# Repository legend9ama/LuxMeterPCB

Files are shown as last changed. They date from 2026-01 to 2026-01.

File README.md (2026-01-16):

# LuxMeter v1.0 - Hardware Datasheet

<div align="center">
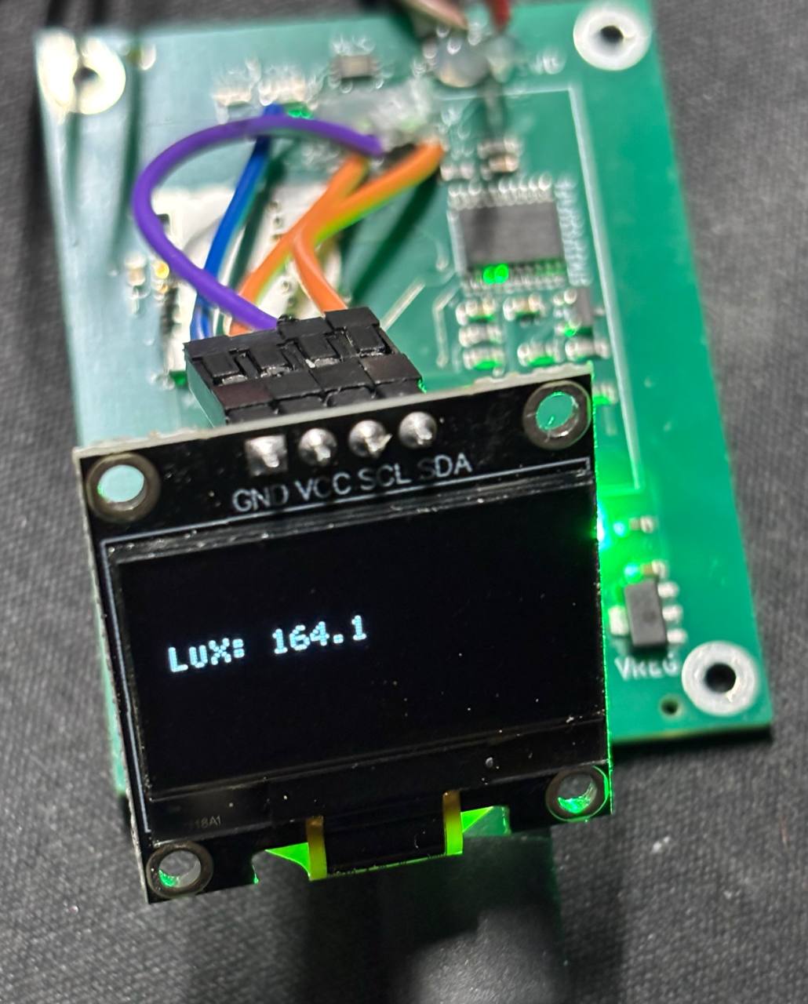
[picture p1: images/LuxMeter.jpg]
LuxMeter
  
</div>

**LuxMeter** started as a PCB design assignment for my *Fundamentals of Electronics* course.

The requirement was just to submit the layout files, but I decided to go all the way. I ordered the PCBAs and wrote the firmware.

This repository contains the hardware design files (KiCad), schematics, and manufacturing data.

---

## 📸 Gallery

| Top View | Bottom View |
| :---: | :---: |
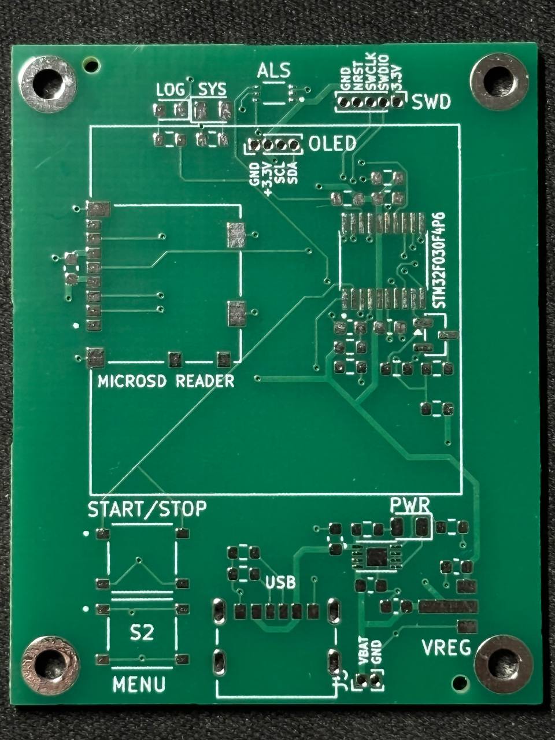
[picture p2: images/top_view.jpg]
PCB Top View
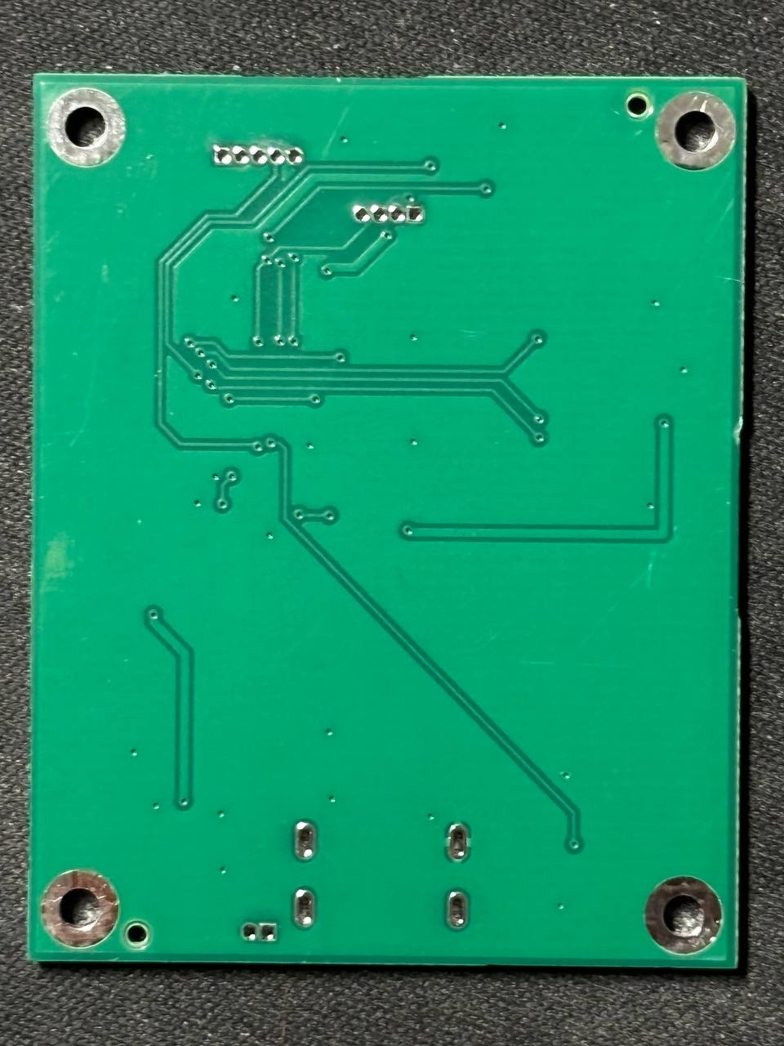
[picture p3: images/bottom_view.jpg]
PCB Bottom View
|  | 

---

## 📐 Circuit Diagram (Schematic)

The full schematic design is available in the [`LuxMeter/`](./LuxMeter) folder.
<div align="center">
  Schematic
</div>

---

## 🛠 Hardware Specifications

### Component Overview
Datasheets for key components are stored locally in the [`docs/`](./docs) directory.

| Component | Part Number | Function | Interface | Datasheet |
| :--- | :--- | :--- | :--- | :--- |
| **MCU** | **STM32F030F4P6** | Main Controller (Cortex-M0) | - | [View PDF](./docs/stm32f030f4.pdf) |
| **Sensor** | **BH1750FVI** | Digital Light Sensor | I2C1 | [View PDF](./docs/bh1750fvi-e-186247.pdf) |
| **Display** | **SSD1306 / SH1106** | 0.96" OLED Module | I2C1 | [View PDF](./docs/ssd1306.pdf) |
| **SD Slot** | **Molex 104031-0811** | MicroSD Card Connector | SPI1 | [View PDF](./docs/1040310811_sd.pdf) |
| **Charger** | **MCP73831** | Li-Po Charge Controller | - | [View PDF](./docs/MCP73831-Family-Data-Sheet-DS20001984H.pdf) |
| **LDO** | **MCP1700-3.3V** | Voltage Regulator | - | [View PDF](./docs/MCP1700-Data-Sheet-20001826F.pdf) |
| **MOSFET** | **2N7002** | Battery Monitor Switch | GPIO | [View PDF](./docs/NDS7002A-D.PDF) |

---

## 🔌 GPIO Map (Bare Metal)

### GPIO Table

| Pin | Name | Schematic Label | Function | Active Level / Notes |
| :--- | :--- | :--- | :--- | :--- |
| **PF0** | `BTN_1` | `BTN_1` | User Button 1 | **Low** (Requires Internal Pull-Up) |
| **PF1** | `BTN_2` | `BTN_2` | User Button 2 | **Low** (Requires Internal Pull-Up) |
| **PA0** | `BATT_MON` | `BATT_MON` | ADC Input (Chan 0) | Analog Voltage (Divided by 2) |
| **PA1** | `LED_R` | `LED_R` | User LED (Red) | **High** |
| **PA2** | `BH_RST` | `BH_RST` | Sensor Reset / DVI | Check BH1750 Datasheet |
| **PA3** | `BATT_EN` | `BATT_EN` | Battery Monitor Enable | **High** (Enable measurement) |
| **PA4** | `SD_CS` | `SD_CS` | MicroSD Chip Select | **Low** (Software Controlled) |
| **PA5** | `SPI1_SCK` | `SPI1_SCK` | SPI Clock | AF0 |
| **PA6** | `SPI1_MISO` | `SPI1_MISO` | SPI MISO | AF0 |
| **PA7** | `SPI1_MOSI` | `SPI1_MOSI` | SPI MOSI | AF0 |
| **PB1** | `LED_G` | `LED_G` | User LED (Green) | **High** |
| **PA9** | `I2C1_SCL` | `I2C1_SCL` | I2C Clock | AF4 (Open-Drain) |
| **PA10** | `I2C1_SDA` | `I2C1_SDA` | I2C Data | AF4 (Open-Drain) |
| **PA13** | `SWDIO` | `SWDIO` | SWD Debug Data |  |
| **PA14** | `SWCLK` | `SWCLK` | SWD Debug Clock | |

---

## ⚙️ Subsystem Details

### 1. Battery Monitoring
To extend battery life, the voltage divider (100kΩ/100kΩ) is disconnected via a MOSFET (`Q1`) when not in use.

* **Formula:** $V_{batt} = ADC_{val} \times \frac{3.3V}{4095} \times 2$
* **Sequence:**
    1.  Set `PA2` HIGH.
    2.  Wait ~1ms for stabilization.
    3.  Read ADC on `PA0`.
    4.  Set `PA2` LOW immediately.

### 2. MicroSD Interface (Molex 104031-0811)
The board uses a push-push type Molex connector.
* **Bus:** SPI1 (max 18 Mbps, start initialization at <400 kHz).
* **Card Detect:** Not physically connected. Use software polling (try to mount) to detect card insertion.

### 3. I2C Bus (Sensors)
* **BH1750 Address:** `0x23` (ADDR pin grounded).
* **OLED Address:** Typically `0x3C` (verify with I2C scanner).

---

## ⚠️ Errata & Assembly Notes (Rev 1.0)

**Important notes for assembling the v1.0 PCB:**

1.  **Capacitor C6 Interference:**
    * **Issue:** The decoupling capacitor `C6` is placed directly in the insertion path of the MicroSD card. The physical height of the component blocks the card from entering the Molex slot.
    * **Workaround:** Simply remove (desolder) `C6`. The SD card interface functions correctly without it.
    
2.  **Incorrect Connector Pitch (OLED & SWD):**
    * **Issue:** The through-hole footprints for the **OLED Display** and **SWD Debug** header connectors were incorrectly assigned a **1.0mm pitch** instead of the standard **2.54mm**.
    * **Workaround:** I soldered wires directly to the connectors.

---

## 📂 Repository Structure

* `LuxMeter/` — Original KiCad project files (Schematic & PCB).
* `gerbers/` — Production files (Gerber/Drill) for ordering PCBs.
* `docs/` — PDF datasheets for components.
* `images/` — Photos and diagrams used in this README.

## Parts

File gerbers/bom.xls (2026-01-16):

Comment | Designator | Footprint | JLCPCB Part #
TS-1187A-B-A-B | S1,S2 | SW_TS-1187A-B-A-B | C318884
LED | D1,D2 | 0805 | C2297
330Ohm | R7,R8 | 0603 | C23138
MCP73831-2ACI_MC | U3 | MCP73831-2ACI_MC | C150772
104031-0811 | J2 | MOLEX_104031-0811 | C585350
USB_C_Receptacle_PowerOnly_6P | J1 | CUI_UJC-HP-3-SMT-TR | C456012
MCP1700T-3302E_MB | U2 | MCP1700T-3302E_MB | C632000
4.7μF | C1,C2,C4 | 0603 | C19666
100kOhm | R10,R9 | 0603 | C25803
2N7002 | Q1 | SOT-23 | C8545
10kOhm | R11,R4,R6 | 0603 | C25804
0.1μF | C5,C6,C7,C8 | 0603 | C14663
5.1kOhm | R2,R3 | 0603 | C23186
LED | D3 | 0603 | C2286
4.7kOhm | R12,R13 | 0603 | C23162
6.8kOhm | R5 | 0603 | C23212
1μF | C3 | 0603 | C15849
BH1750FVI-TR | U1 | XDCR_BH1750FVI-TR | C78960
STM32F030F4P6 | U4 | SOP65P640X120-20N | C89040
1kOhm | R1 | 0603 | C21190

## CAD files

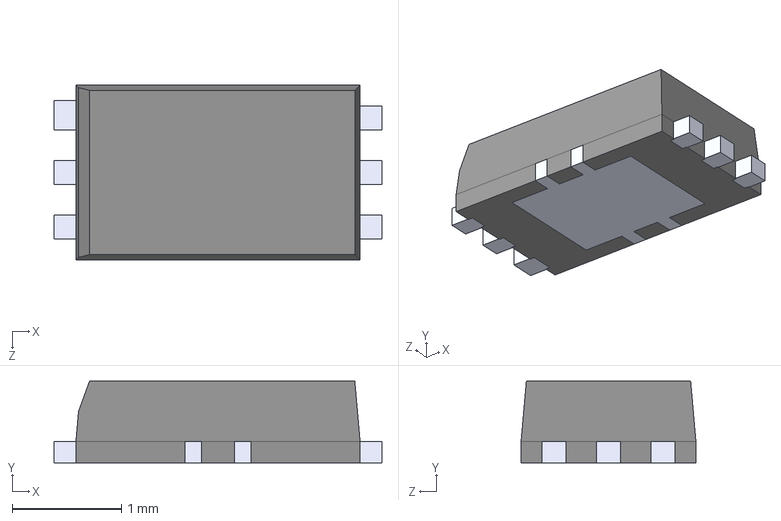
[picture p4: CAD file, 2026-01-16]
LuxMeter/BH1750FVI/BH1750FVI-TR.step
3.00 x 0.75 x 1.60 mm

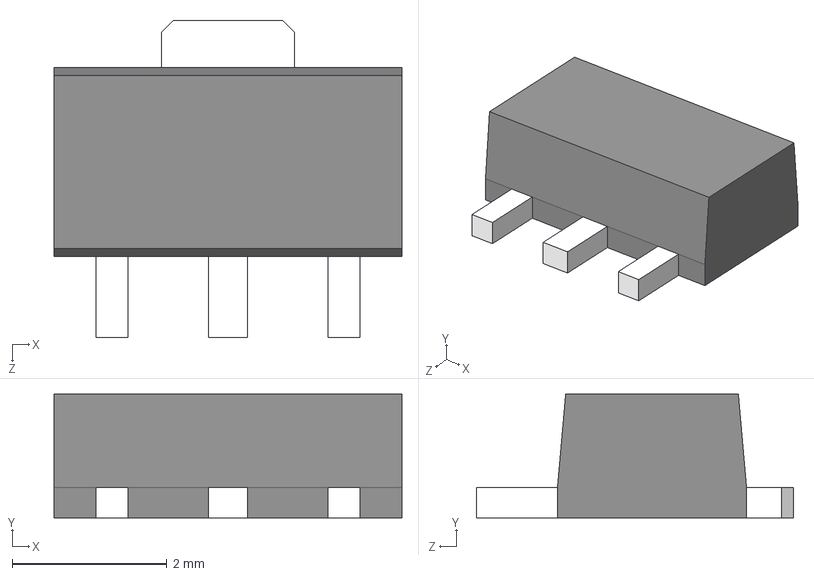
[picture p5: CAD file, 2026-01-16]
LuxMeter/MCP1700-3302E/MCP1700T-3302E_MB.step
4.50 x 1.60 x 4.10 mm

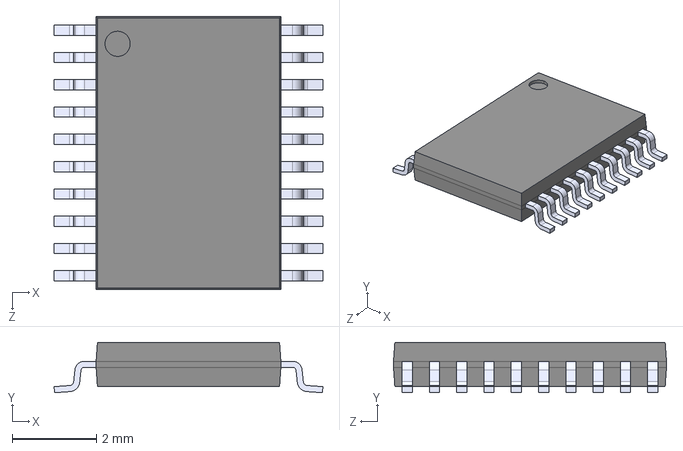
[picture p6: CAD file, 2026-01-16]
LuxMeter/STM32F030F4P6/STM32F030F4P6.step
6.40 x 1.20 x 6.50 mm

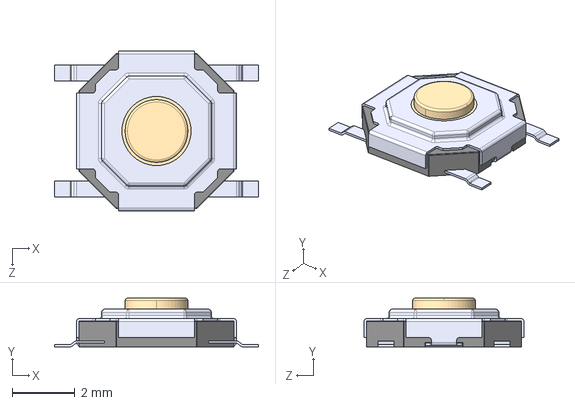
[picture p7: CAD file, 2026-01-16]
LuxMeter/TS-1187A-B-A-B/.STEP
6.50 x 1.55 x 5.10 mm

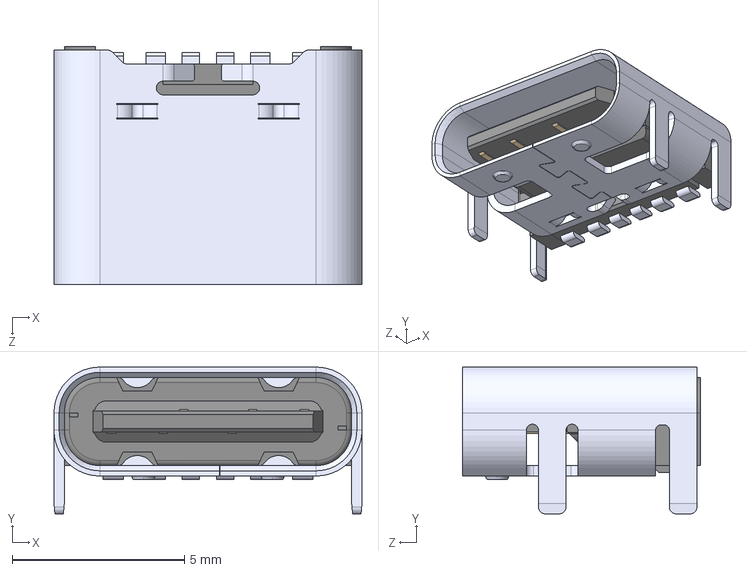
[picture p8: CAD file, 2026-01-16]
LuxMeter/UJC-HP-3-SMT-TR/UJC-HP-3-SMT-TR.step
8.94 x 4.26 x 6.90 mm

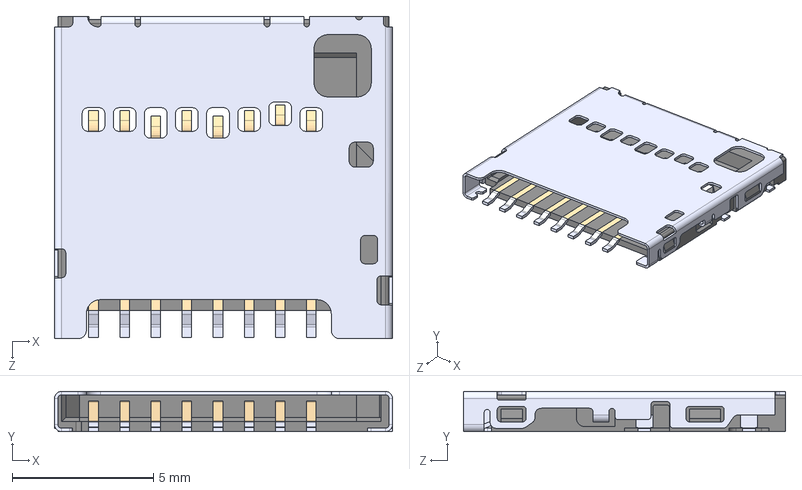
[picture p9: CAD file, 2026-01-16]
LuxMeter/104031-0811/104031-0811.step
12.0 x 1.42 x 11.4 mm

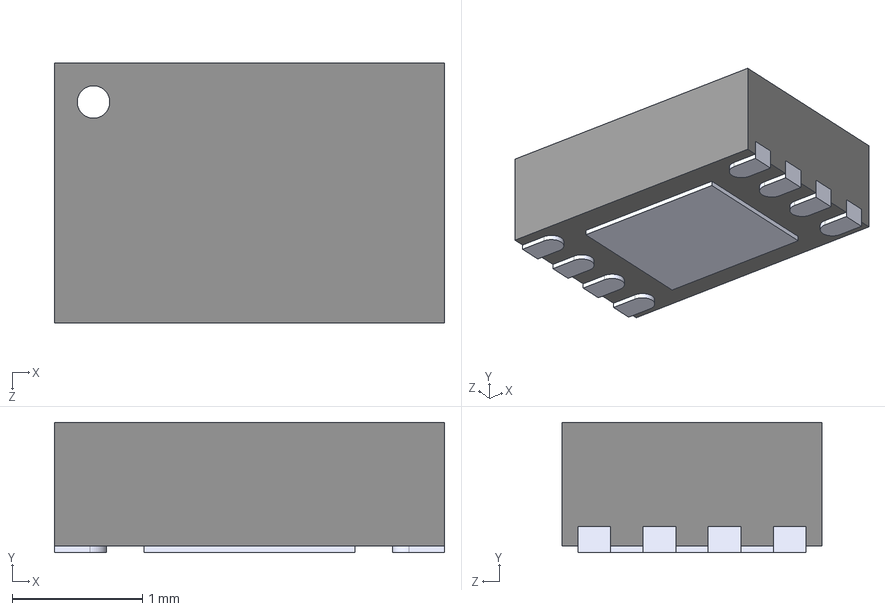
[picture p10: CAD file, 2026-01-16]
LuxMeter/MCP73831-2/MCP73831-2ACI_MC.step
3.00 x 1.00 x 2.00 mm

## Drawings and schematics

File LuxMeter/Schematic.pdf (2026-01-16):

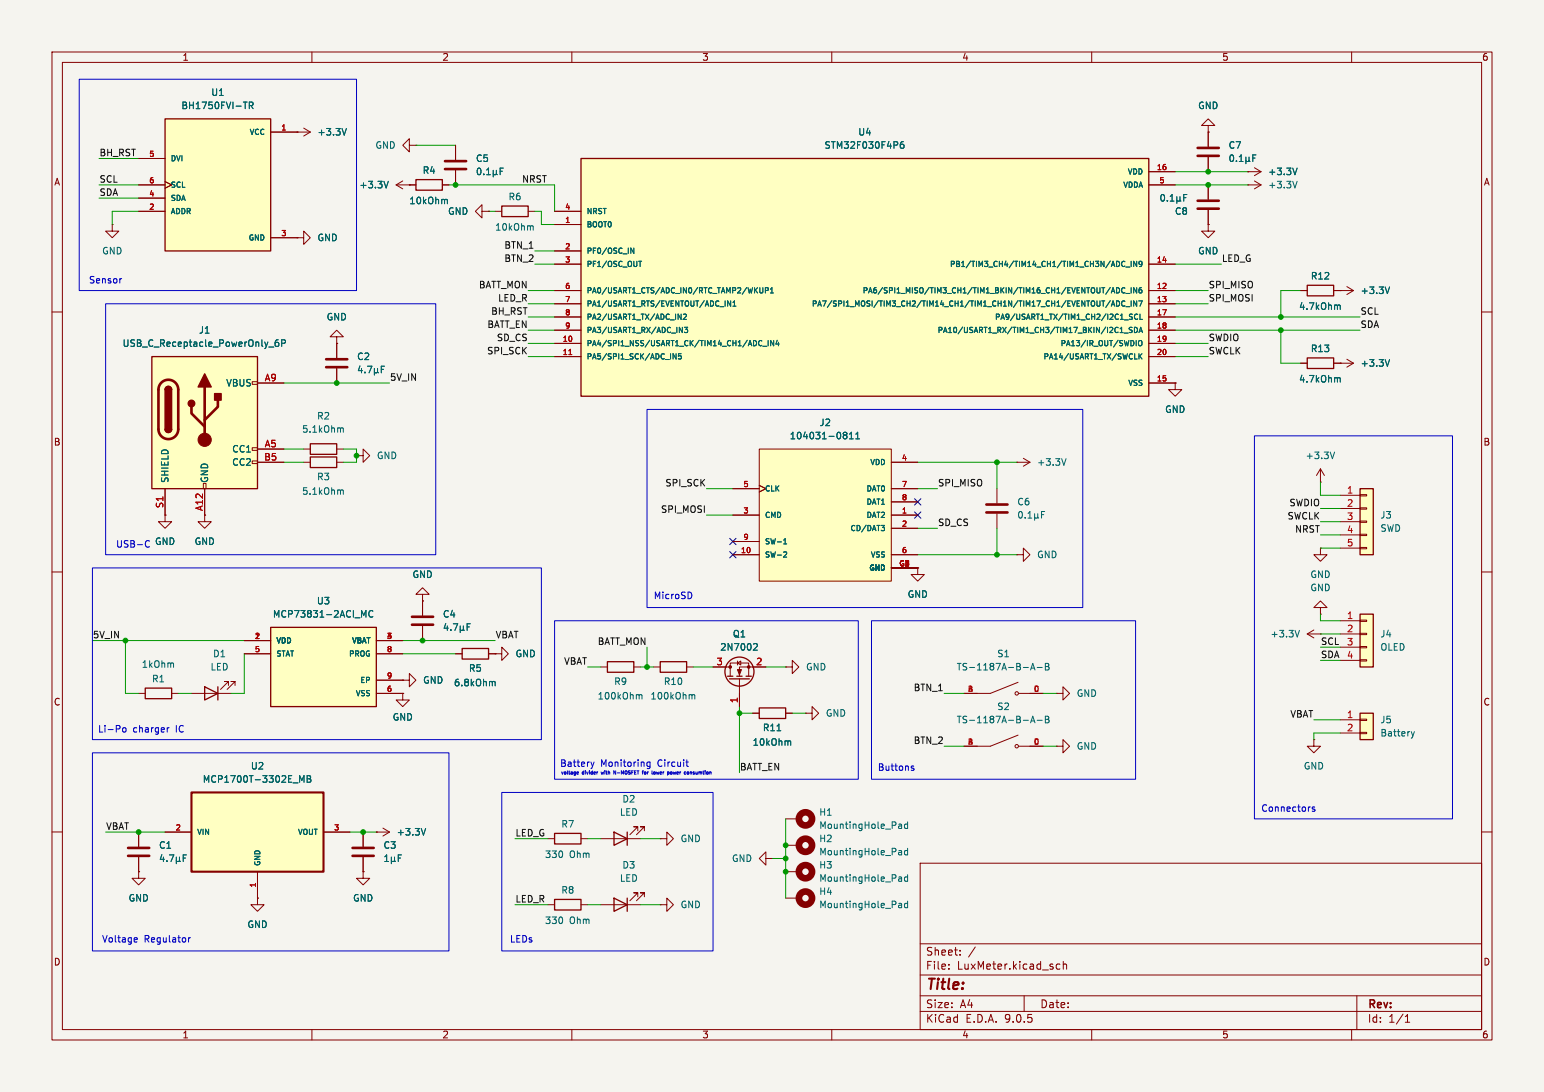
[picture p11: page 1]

Id: 1/1 Title: File: LuxMeter.kicad_sch Sheet: /

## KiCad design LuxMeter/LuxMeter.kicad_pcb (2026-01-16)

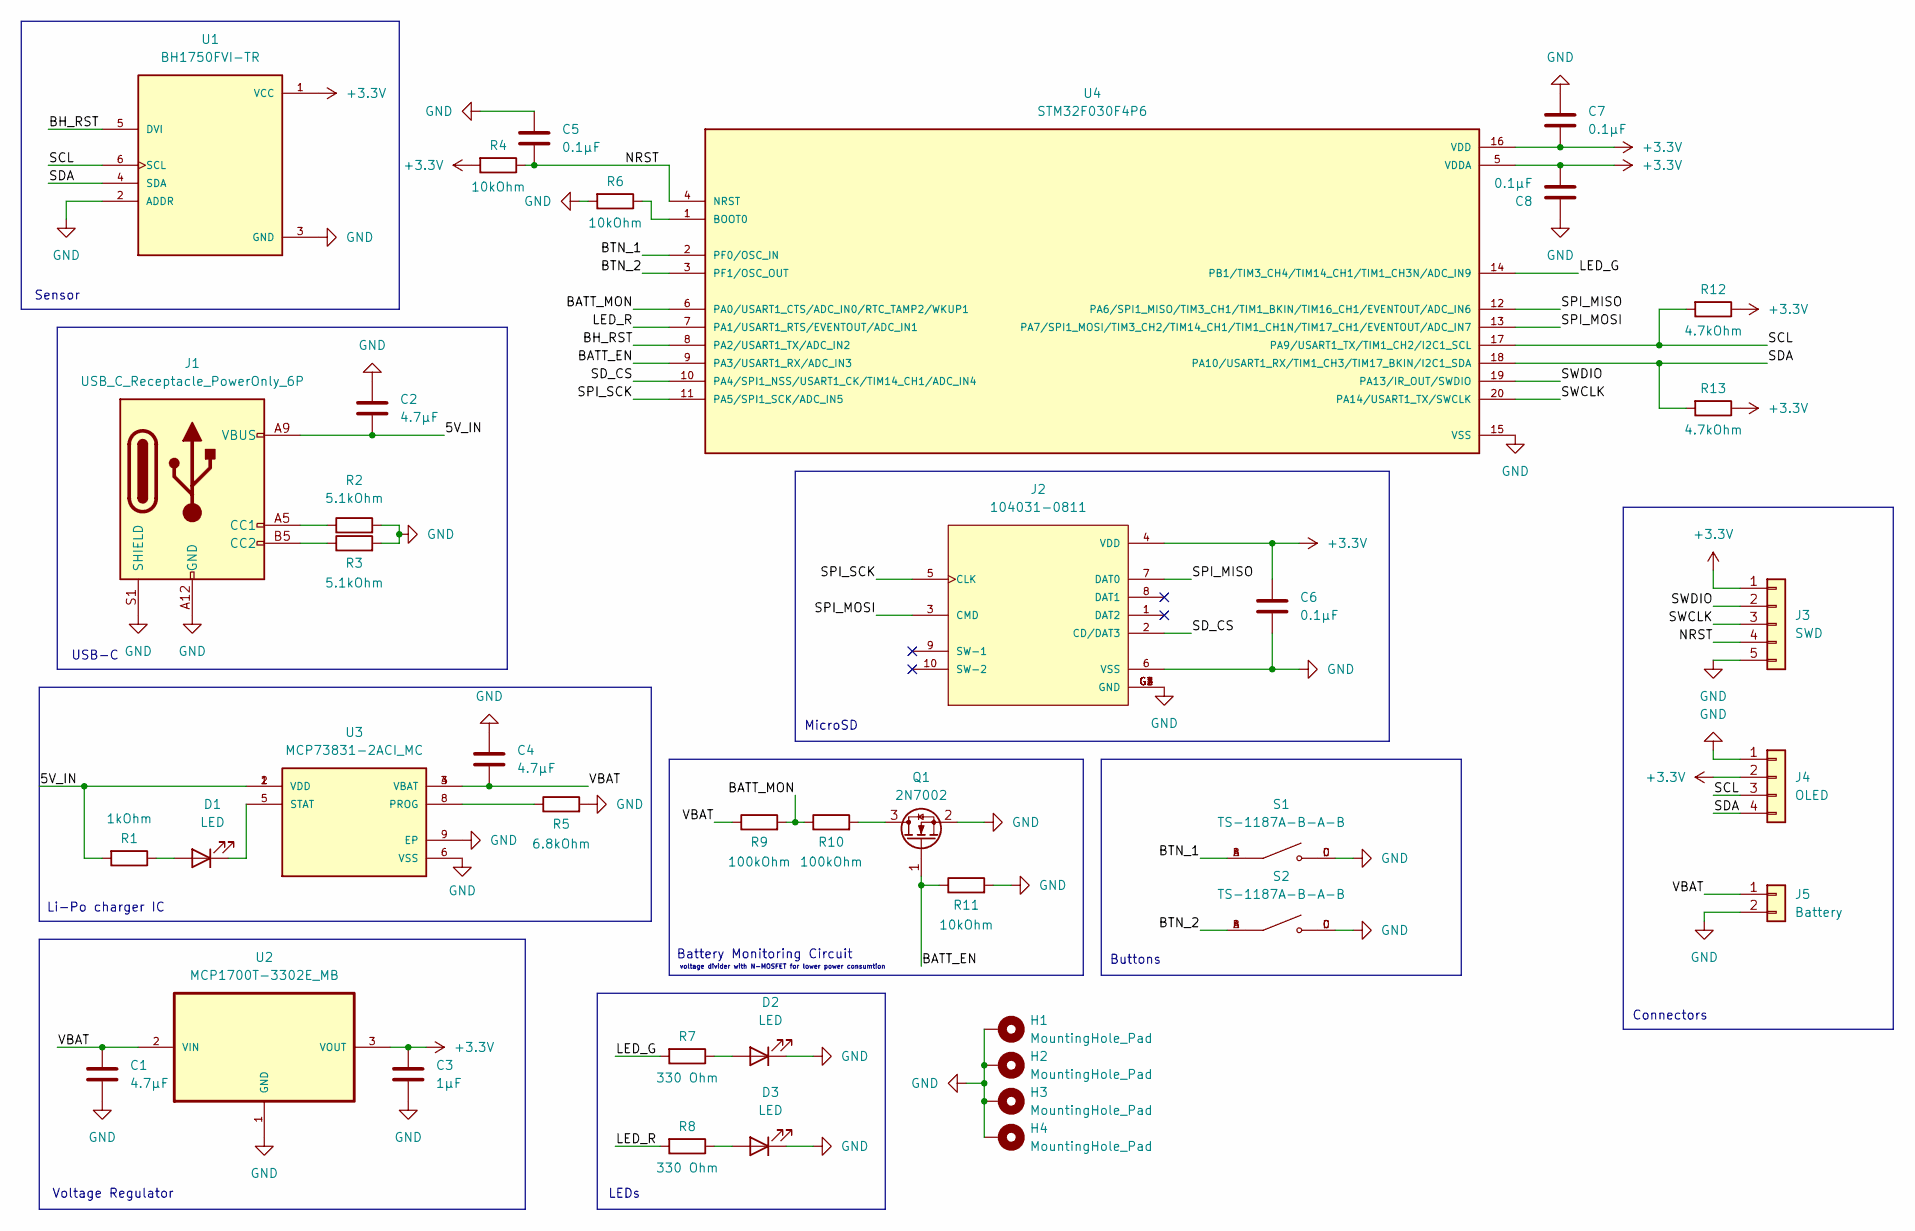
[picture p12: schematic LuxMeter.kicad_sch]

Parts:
C1, C2, C4: 4.7μF; C_0603_1608Metric
C3: 1μF; C_0603_1608Metric
C5, C6, C7, C8: 0.1μF; C_0603_1608Metric
D1, D2: LED; LED_0805_2012Metric
D3: LED; LED_0603_1608Metric
H1, H2, H3, H4: MountingHole_Pad; MountingHole_2.2mm_M2_Pad
J1: USB_C_Receptacle_PowerOnly_6P; CUI_UJC-HP-3-SMT-TR
J2: 104031-0811; MOLEX_104031-0811; PARTREV B2
J3: SWD; PinHeader_1x05_P1.00mm_Vertical
J4: OLED; PinHeader_1x04_P1.00mm_Vertical
J5: Battery; PinHeader_1x03_P1.00mm_Vertical
Q1: 2N7002; SOT-23
R1: 1kOhm; R_0603_1608Metric
R2, R3: 5.1kOhm; R_0603_1608Metric
R4, R6, R11: 10kOhm; R_0603_1608Metric
R5: 6.8kOhm; R_0603_1608Metric
R7, R8: 330 Ohm; R_0603_1608Metric
R9, R10: 100kOhm; R_0603_1608Metric
R12, R13: 4.7kOhm; R_0603_1608Metric
S1, S2: TS-1187A-B-A-B; SW_TS-1187A-B-A-B; PARTREV A0
U1: BH1750FVI-TR; XDCR_BH1750FVI-TR; PARTREV D
U2: MCP1700T-3302E_MB
U3: MCP73831-2ACI_MC; PARTREV G
U4: STM32F030F4P6; SOP65P640X120-20N

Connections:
+3.3V: C3.1, C6.1, C7.1, C8.1, J2.4 (VDD), J3.1, J4.2, R4.2, R12.1, R13.1, U1.1 (VCC), U2.3 (VOUT), U4.5 (VDDA), U4.16 (VDD)
/5V_IN: C2.1, J1.A9 (VBUS), J1.B9 (VBUS), R1.2, U3.1 (VDD), U3.2 (VDD)
/BATT_EN: Q1.1 (G), R11.1, U4.9 (PA3/USART1_RX/ADC_IN3)
/BATT_MON: R9.2, R10.1, U4.6 (PA0/USART1_CTS/ADC_IN0/RTC_TAMP2/WKUP1)
/BH_RST: U1.5 (DVI), U4.8 (PA2/USART1_TX/ADC_IN2)
/BTN_1: S1.A, S1.B, U4.2 (PF0/OSC_IN)
/BTN_2: S2.A, S2.B, U4.3 (PF1/OSC_OUT)
/LED_G: R7.2, U4.14 (PB1/TIM3_CH4/TIM14_CH1/TIM1_CH3N/ADC_IN9)
/LED_R: R8.2, U4.7 (PA1/USART1_RTS/EVENTOUT/ADC_IN1)
/NRST: C5.1, J3.4, R4.1, U4.4 (NRST)
/SCL: J4.3, R12.2, U1.6 (SCL), U4.17 (PA9/USART1_TX/TIM1_CH2/I2C1_SCL)
/SDA: J4.4, R13.2, U1.4 (SDA), U4.18 (PA10/USART1_RX/TIM1_CH3/TIM17_BKIN/I2C1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)
/SD_CS: J2.2 (CD/DAT3), U4.10 (PA4/SPI1_NSS/USART1_CK/TIM14_CH1/ADC_IN4)
/SPI_MISO: J2.7 (DAT0), U4.12 (PA6/SPI1_MISO/TIM3_CH1/TIM1_BKIN/TIM16_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)
/SPI_MOSI: J2.3 (CMD), U4.13 (PA7/SPI1_MOSI/TIM3_CH2/TIM14_CH1/TIM1_C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)
/SPI_SCK: J2.5 (CLK), U4.11 (PA5/SPI1_SCK/ADC_IN5)
/SWCLK: J3.3, U4.20 (PA14/USART1_TX/SWCLK)
/SWDIO: J3.2, U4.19 (PA13/IR_OUT/SWDIO)
/VBAT: C1.1, C4.2, J5.1, R9.1, U2.2 (VIN), U3.3 (VBAT), U3.4 (VBAT)
GND: C1.2, C2.2, C3.2, C4.1, C5.2, C6.2, C7.2, C8.2, D2.1 (K), D3.1 (K), H1.1, H2.1, H3.1, H4.1, J1.A12 (GND), J1.B12 (GND), J1.S1 (SHIELD), J2.6 (VSS), J2.G1 (GND), J2.G2 (GND), J2.G3 (GND), J2.G4 (GND), J3.5, J4.1, J5.2, Q1.2 (S), R2.2, R3.2, R5.2, R6.2, R11.2, S1.C, S1.D, S2.C, S2.D, U1.2 (ADDR), U1.3 (GND), U2.1 (GND), U3.6 (VSS), U3.9 (EP), U4.15 (VSS)
unnamed: D1.2 (A), R1.1
unnamed: D1.1 (K), U3.5 (STAT)
unnamed: D2.2 (A), R7.1
unnamed: D3.2 (A), R8.1
unnamed: J1.A5 (CC1), R2.1
unnamed: J1.B5 (CC2), R3.1
unnamed: Q1.3 (D), R10.2
unnamed: R5.1, U3.8 (PROG)
unnamed: R6.1, U4.1 (BOOT0)

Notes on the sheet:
voltage divider with N-MOSFET for lower power consumtion
Battery Monitoring Circuit
Connectors
USB-C
Voltage Regulator
Li-Po charger IC
Buttons
MicroSD
Sensor
LEDs

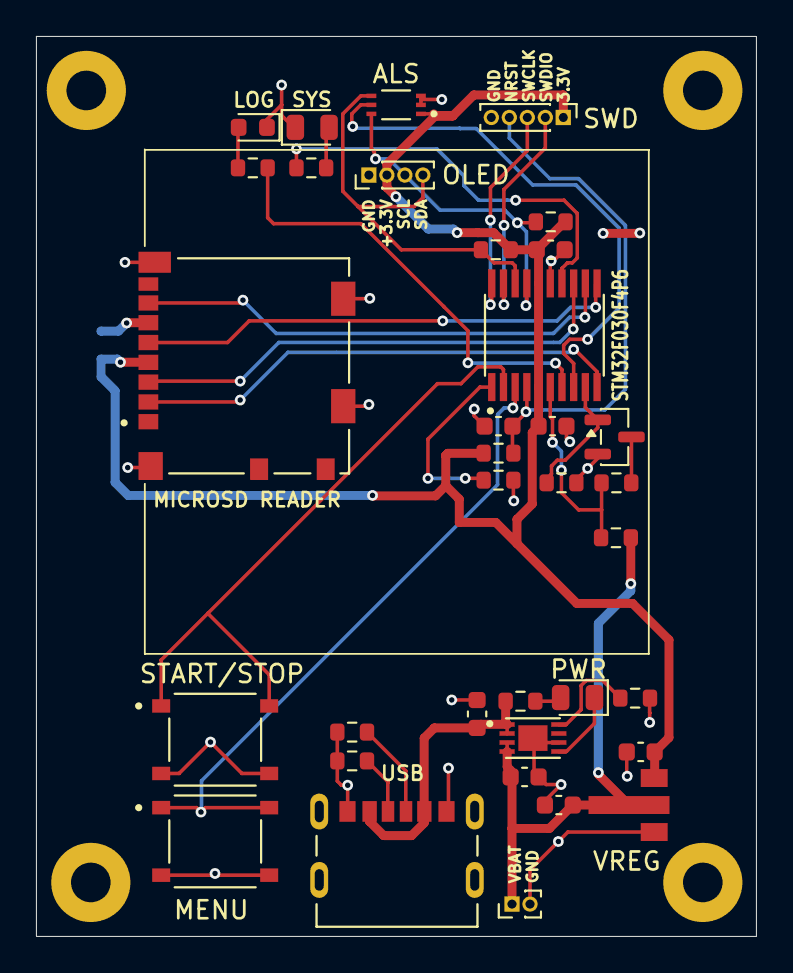
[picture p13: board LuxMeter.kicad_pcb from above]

Board: 2 copper layers, 40.0 x 50.0 mm, 40 parts (1 on the bottom side), 29 nets.
